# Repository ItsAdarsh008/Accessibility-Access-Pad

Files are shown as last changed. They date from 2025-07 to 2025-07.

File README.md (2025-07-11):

# AccessibilityAccessPad by Adarsh

AAPad is an 8 key macropad with a rotary encoder, an OLED Display. It also has 9 WS2812B Leds, and uses QMK firmware

It serves as a plug & play device integrated with the Windows accessibility toolkit in order to allow computer-illiterate users use of accessibility features (i.e. high contrast mode). 

## Features:
- Dual layer PLA case (hopefully made out of wood, later)
- Plexiglass window, displaying the diodes and silkscreened logo on the PCB (also my glasses )
- 128x32 OLED Display, to allow bystanders to assist the user whenever necessary
- EC11 Rotary encoder, for tactile feedback
- 9 WS2812B RGB LEDs. One for the accessibility icon, and the rest for backlighting
- 8 Keys (for functions, see below)

## Planned Features:
- [VIA](https://www.caniusevia.com/) support!
- Reactive backlight for each key

## CAD Model:
Everything fits together using 6 M3 Bolts and heatset inserts. 4 for the case, two for the PCB.

It has 2 separate printed pieces. The base, where the PCB is mounted, and the cover.

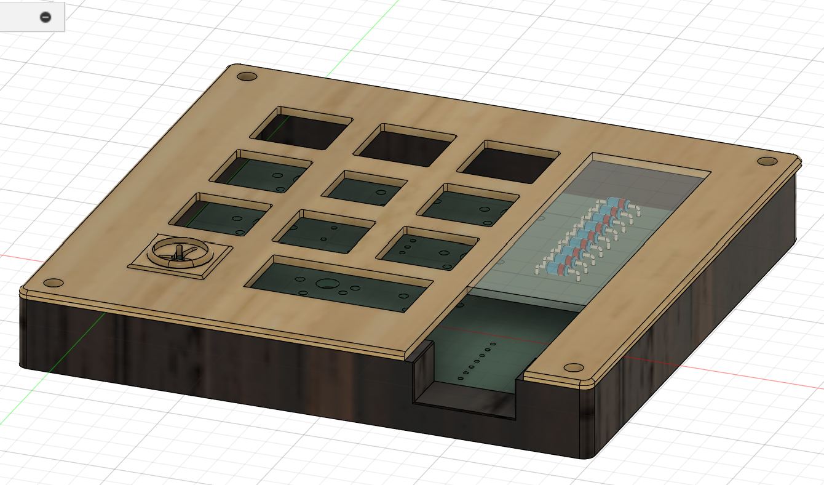
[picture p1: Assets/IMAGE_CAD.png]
3D Cad Model


Made in Fusion360. First time using it!

## PCB
Here's my PCB! It was made in KiCad. The silkscreen(s) was imported from Canva. I also put a quote on the top right, because why not?

Schematic
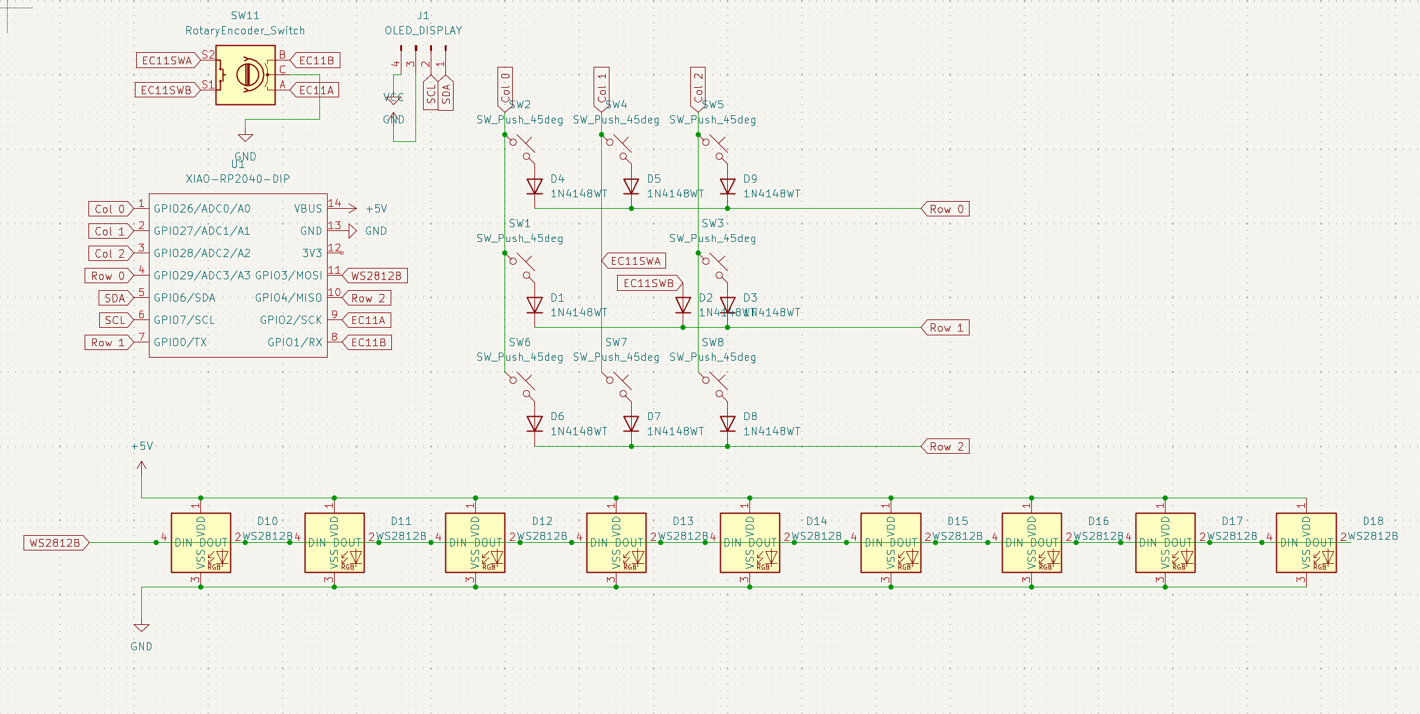
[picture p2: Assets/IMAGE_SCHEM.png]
Schematic


PCB
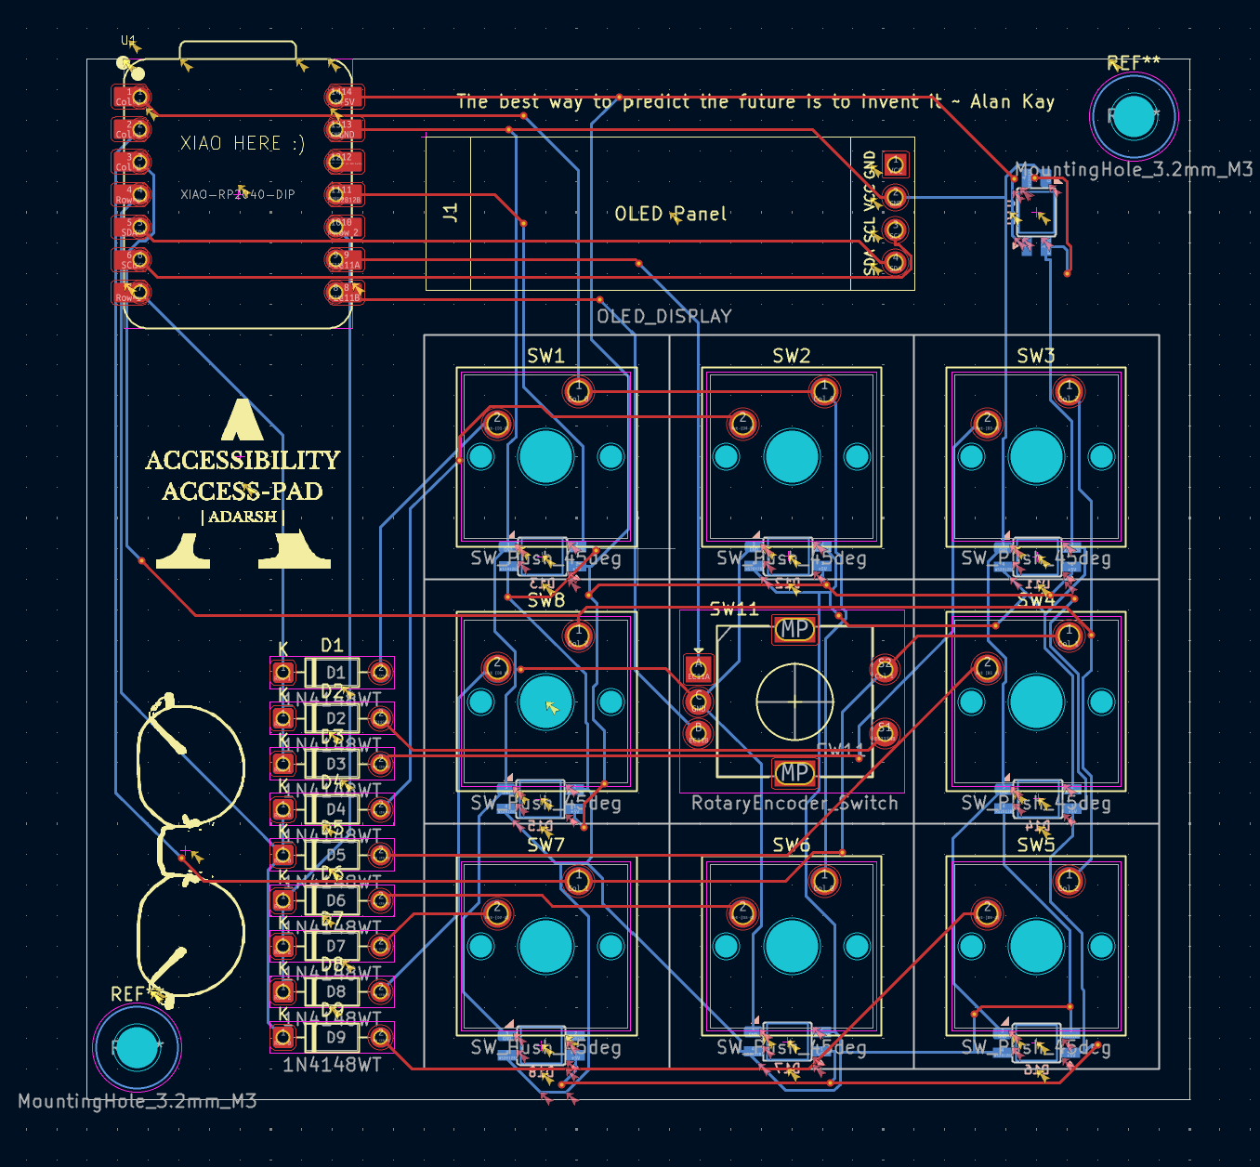
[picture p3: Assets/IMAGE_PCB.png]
PCB


## Firmware Overview
This hackpad uses [QMK](https://qmk.fm/) firmware for everything. 

- The rotary encoder changes volume, press to mute

- The 8 keys currently act as functions/macros I preassigned in QMK.
    1. Text-to-Speech (TTS) Toggle
        - Reads aloud selected text on screen
    2. Zoom In
    3. Zoom Out
    4. Speech-to-Text Activation
        - Starts or stops dictation mode to convert speech into text
    5. Adjusts Cursor Speed
    6. Activates Computer speakers to announce a custom message (preset "I need assistance")
    7. High Contrast Mode Toggle
    8. Opens Accessibility Settings Window

- The OLED reads out the function of a button whenever it is pressed. The goal is so that any bystander who is called to assist the user may know what the device is suppose to be doing at any given input.

- *Note*: **Please suggest any new functions for each key!!** I have a very limited understanding of accessibility needs at the moment, though I hope my preset functions serve you well.

## BOM:
Here should be everything you need to make this hackpad

- 8x Cherry MX Style Switches
- 8x DSA Keycaps
- 6x M3x5x4 Heatset inserts
- 3x M3x16mm SHCS Bolts
- 9x 1N4148 DO-35 Diodes.
- 9x WS2812B LEDs
- 1x 0.91" 128x32 OLED Display
- 1x EC11 Rotary Encoder
- 1x XIAO RP2040
- 1x Case (2 printed parts, PLA)

## Extra stuff
Thanks so much for reading to the end, this is my first real hardware project. Stay tuned to my GitHub for more :\)\)

~ Adarsh

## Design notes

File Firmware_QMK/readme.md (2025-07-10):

# accessibilityaccesspad

accessibilityaccesspad

*A short description of the keyboard/project*

* Keyboard Maintainer: [Adarsh](https://github.com/ItsAdarsh008)
* Hardware Supported: *The PCBs, controllers supported*
* Hardware Availability: *Links to where you can find this hardware*

Make example for this keyboard (after setting up your build environment):

    make accessibilityaccesspad:default

Flashing example for this keyboard:

    make accessibilityaccesspad:default:flash

See the [build environment setup](https://docs.qmk.fm/#/getting_started_build_tools) and the [make instructions](https://docs.qmk.fm/#/getting_started_make_guide) for more information. Brand new to QMK? Start with our [Complete Newbs Guide](https://docs.qmk.fm/#/newbs).

## Bootloader

Enter the bootloader in 3 ways:

* **Bootmagic reset**: Hold down the key at (0,0) in the matrix (usually the top left key or Escape) and plug in the keyboard
* **Physical reset button**: Briefly press the button on the back of the PCB - some may have pads you must short instead
* **Keycode in layout**: Press the key mapped to `QK_BOOT` if it is available

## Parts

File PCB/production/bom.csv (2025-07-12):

Designator | Footprint | Quantity | Value | LCSC Part #
D1, D2, D3, D4, D5, D6, D7, D8, D9 | D_DO-35_SOD27_P7.62mm_Horizontal | 9 | 1N4148WT
D10, D11, D12, D13, D14, D15, D16, D17, D18 | SK6812-MINI-E | 9 | WS2812B
J1 | SSD1306-0.91-OLED-4pin-128x32 | 1 | OLED_DISPLAY
SW1, SW2, SW3, SW4, SW5, SW6, SW7, SW8 | SW_Cherry_MX_1.00u_PCB | 8 | SW_Push_45deg
SW11 | RotaryEncoder_Alps_EC11E-Switch_Vertical_H20mm | 1 | RotaryEncoder_Switch
U1 | XIAO-RP2040-DIP | 1 | XIAO-RP2040-DIP

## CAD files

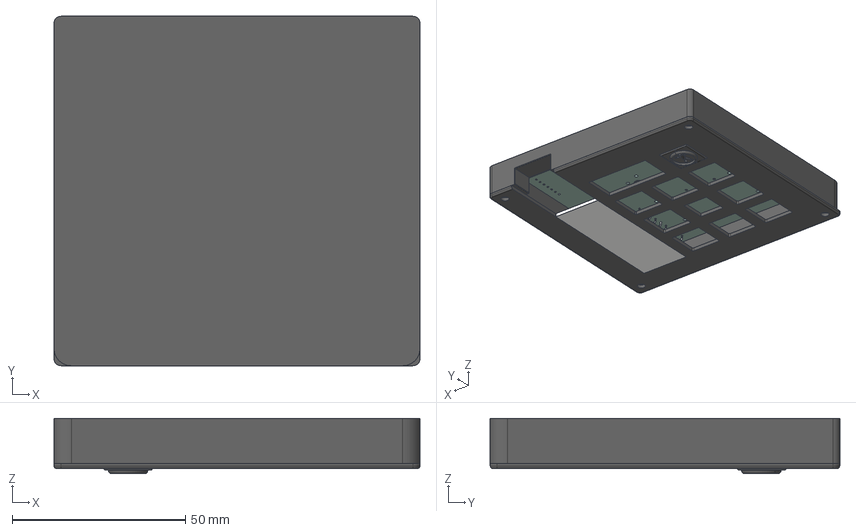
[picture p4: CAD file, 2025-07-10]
CAD/AA_CAD.step
105.7 x 101.0 x 16.0 mm
D_DO-35_SOD27_P7.62mm_Horizontal x 9
MacroPadBackUp2_PCB

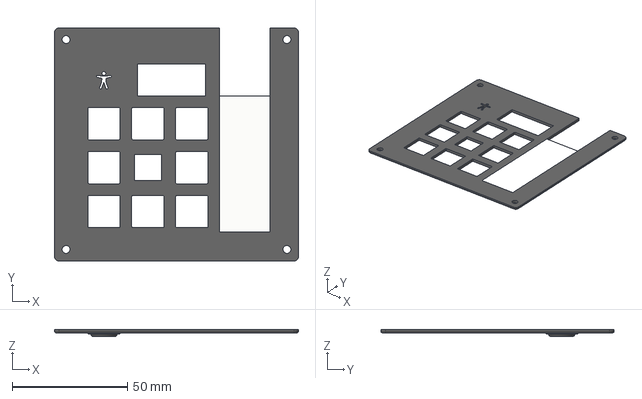
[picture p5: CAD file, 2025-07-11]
Production/AA_CAD_Bottom.step
105.7 x 101.0 x 3.00 mm

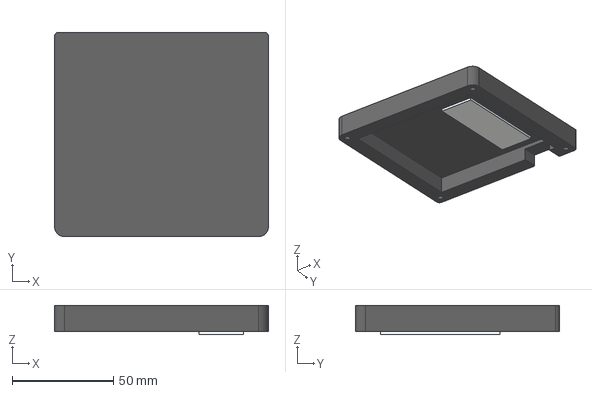
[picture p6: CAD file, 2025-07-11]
Production/AA_CAD_Top.step
105.7 x 101.0 x 14.5 mm

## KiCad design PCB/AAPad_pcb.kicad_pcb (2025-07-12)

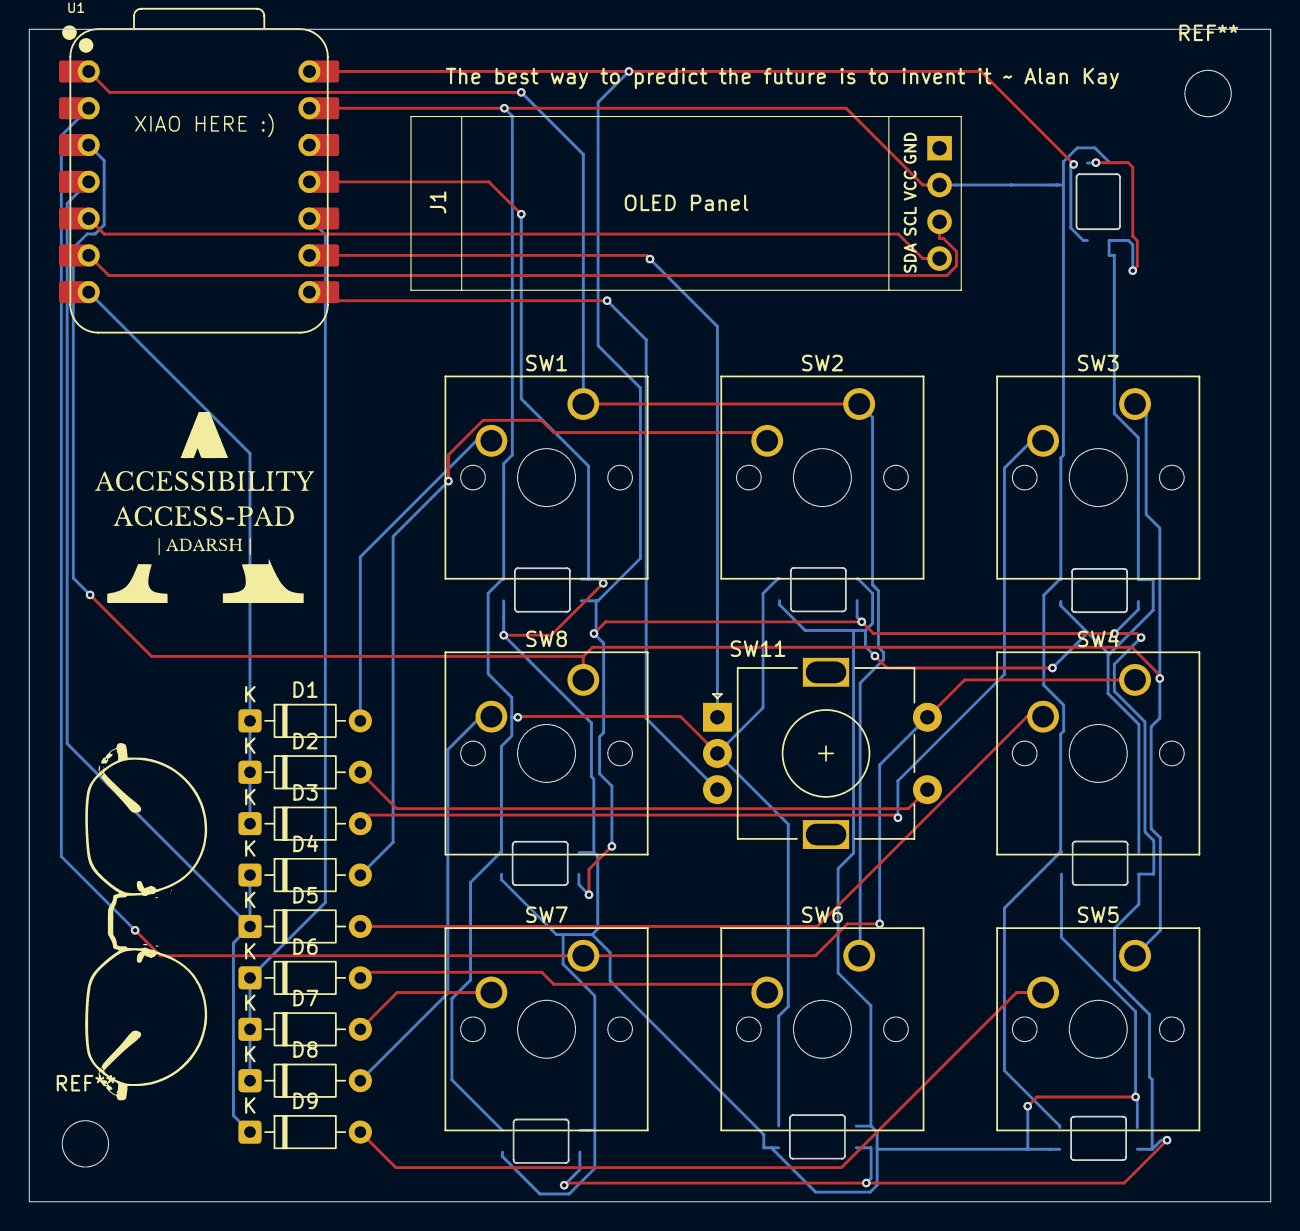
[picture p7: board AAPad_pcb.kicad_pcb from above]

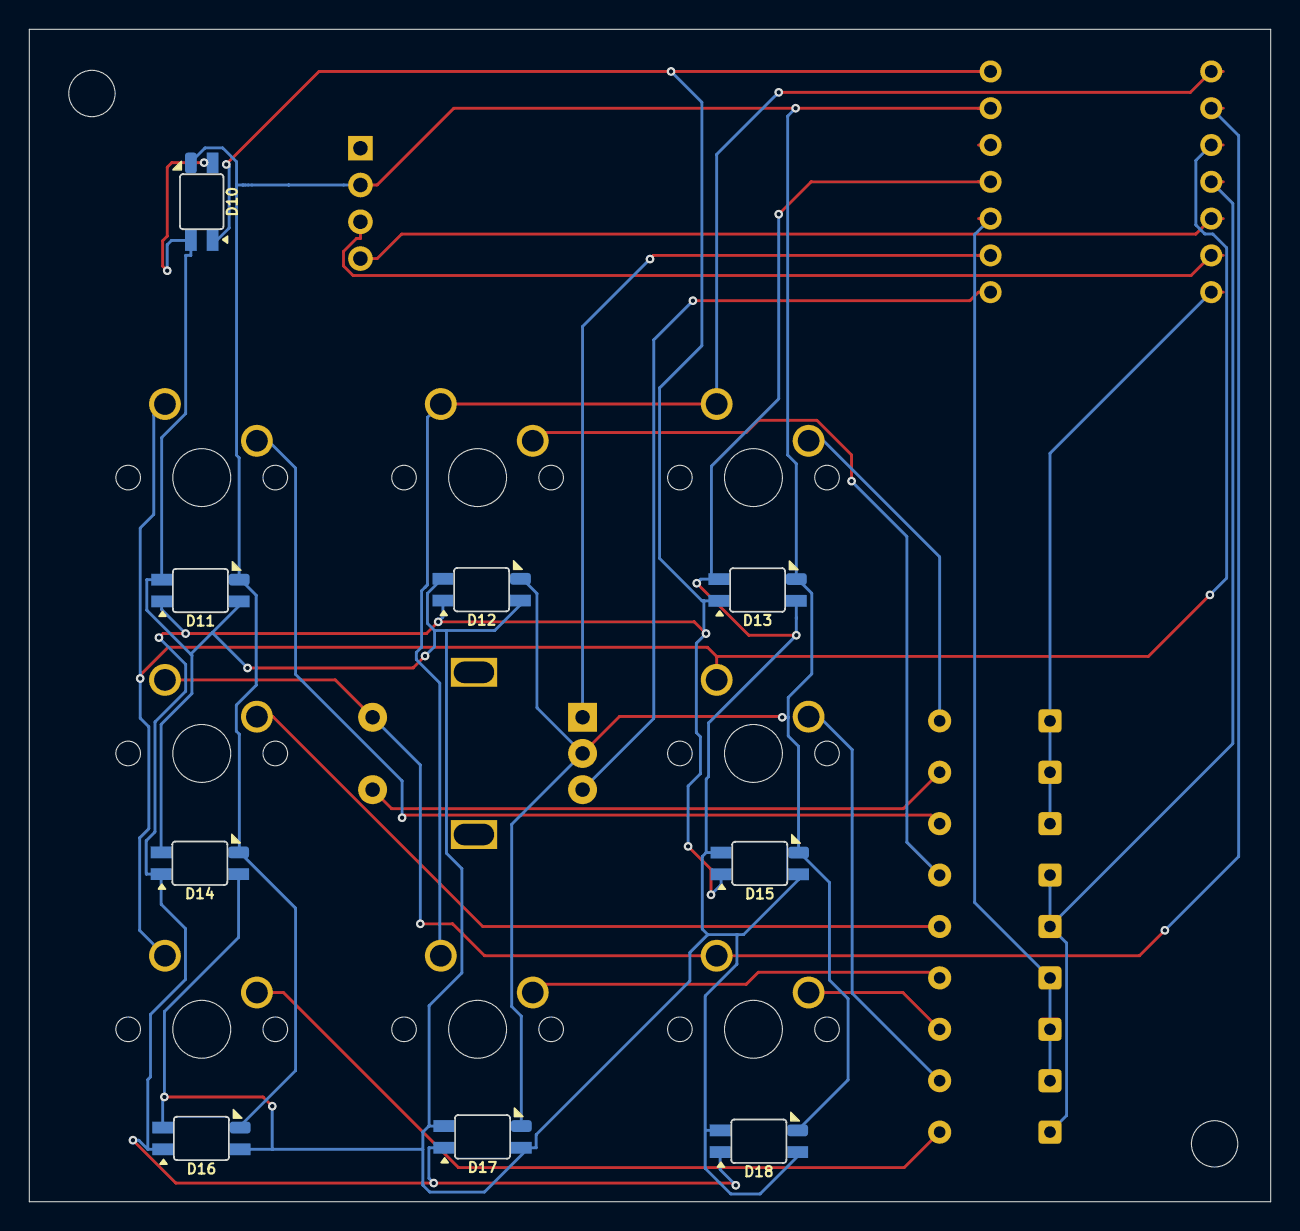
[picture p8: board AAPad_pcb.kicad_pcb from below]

Board: 2 copper layers, 85.7 x 81.0 mm, 29 parts (9 on the bottom side), 22 nets.

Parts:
D1, D2, D3, D4, D5, D6, D7, D8, D9: 1N4148WT; D_DO-35_SOD27_P7.62mm_Horizontal
D10, D11, D12, D13, D14, D15, D16, D17, D18: WS2812B; SK6812-MINI-E
J1: OLED_DISPLAY; SSD1306-0.91-OLED-4pin-128x32
SW1, SW2, SW3, SW4, SW5, SW6, SW7, SW8: SW_Push_45deg; SW_Cherry_MX_1.00u_PCB
SW11: RotaryEncoder_Switch; RotaryEncoder_Alps_EC11E-Switch_Vertical_H20mm
U1: XIAO-RP2040-DIP

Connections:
+5V: D10.1 (VDD), D11.1 (VDD), D12.1 (VDD), D13.1 (VDD), D14.1 (VDD), D15.1 (VDD), D16.1 (VDD), D17.1 (VDD), D18.1 (VDD), U1.14 (VBUS)
Col 0: SW1.1, SW2.1, SW6.1, U1.1 (GPIO26/ADC0/A0)
Col 1: SW4.1, SW7.1, SW11.S2, U1.2 (GPIO27/ADC1/A1)
Col 2: SW3.1, SW5.1, SW8.1, U1.3 (GPIO28/ADC2/A2)
EC11A: SW11.A, U1.9 (GPIO2/SCK)
EC11B: SW11.B, U1.8 (GPIO1/RX)
EC11SWB: D2.2 (A), SW11.S1
GND: D10.3 (VSS), D11.3 (VSS), D12.3 (VSS), D13.3 (VSS), D14.3 (VSS), D15.3 (VSS), D16.3 (VSS), D17.3 (VSS), D18.3 (VSS), J1.2, SW11.C, U1.13 (GND)
unnamed: D1.2 (A), SW1.2
unnamed: D3.2 (A), SW3.2
unnamed: D4.2 (A), SW2.2
unnamed: D5.2 (A), SW4.2
unnamed: D6.2 (A), SW6.2
unnamed: D7.2 (A), SW7.2
unnamed: D8.2 (A), SW8.2
unnamed: D9.2 (A), SW5.2
Row 0: D4.1 (K), D5.1 (K), D9.1 (K), U1.4 (GPIO29/ADC3/A3)
Row 1: D1.1 (K), D2.1 (K), D3.1 (K), U1.7 (GPIO0/TX)
Row 2: D6.1 (K), D7.1 (K), D8.1 (K), U1.10 (GPIO4/MISO)
SCL: J1.3, U1.6 (GPIO7/SCL)
SDA: J1.4, U1.5 (GPIO6/SDA)
WS2812B: D10.2 (DOUT), D10.4 (DIN), D11.2 (DOUT), D11.4 (DIN), D12.2 (DOUT), D12.4 (DIN), D13.2 (DOUT), D13.4 (DIN), D14.2 (DOUT), D14.4 (DIN), D15.2 (DOUT), D15.4 (DIN), D16.2 (DOUT), D16.4 (DIN), D17.2 (DOUT), D17.4 (DIN), D18.2 (DOUT), D18.4 (DIN), U1.11 (GPIO3/MOSI)

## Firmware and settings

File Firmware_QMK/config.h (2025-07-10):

#define ENCODER_A_PINS { GP2 }
#define ENCODER_B_PINS { GP1 }

#define WS2812_DI_PIN GP3
#define RGBLIGHT_LED_COUNT 9

#define I2C_DRIVER I2CD1
#define I2C1_SDA_PIN GP6
#define I2C1_SCL_PIN GP7

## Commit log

2025-07-10 PCB folder filled in, now awaiting final CAD designs
    [AAAPadSTL.stl, MacroPadBackUp2.kicad_pcb]
2025-07-10 updated CAD file format, added texture for aesthetics
    [AAAPadSTL.stl, AA_CAD.step]
2025-07-10 updated the names of the pcb files for professionalism
    [AAPad_pcb.kicad_pcb]
2025-07-11 Added Gerber Files for Production, ReadMe complete
    [AAPad_pcb-B_Cu.gbr, AAPad_pcb-B_Mask.gbr, AAPad_pcb-B_Paste.gbr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]
2025-07-11 added case production files, compiled firmware
    [AA_CAD_Bottom.step, AA_CAD_Top.step]
2025-07-11 zipped gerber file
    [AAPad_pcb-B_Cu.gbr, AAPad_pcb-B_Mask.gbr, AAPad_pcb-B_Paste.gbr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]
2025-07-11 updated production files once again
    [bom.csv, designators.csv, positions.csv]
2025-07-12 added PCB Backups and slightly altered constraints for PCB
2025-07-12 merged branches
    [AAPad_pcb.kicad_pcb, bom.csv, designators.csv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]
